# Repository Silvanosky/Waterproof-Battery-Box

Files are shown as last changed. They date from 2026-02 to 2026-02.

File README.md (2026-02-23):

# **🔋 Universal Waterproof Battery Box (100% TPU)**

This project provides a fully parametric OpenSCAD model to generate and 3D print waterproof protection boxes for your batteries (18650, 21700, AA, AAA, etc.).  
**The unique feature of this design is that it is specifically designed to be printed in TPU (flexible filament).** Because the material itself acts as a seal, the box integrates a "double radial seal" system (ridges and grooves) directly into its geometry, eliminating the need to buy and add external O-rings.

## **🌟 Features**

* 💧 **100% TPU Printable**: No external O-ring required. Waterproofing is achieved by the compression of the TPU itself.  
* 🛡️ **Integrated Double Radial Seal**: Two compression rings on the flange guarantee an impenetrable barrier to water.  
* 📏 **Universal and Parametric**: Easily select your battery size in OpenSCAD (18650, 20700, 21700, 26650, AA, AAA) or enter your own custom dimensions.  
* 🪶 **Optimized Weight and Time**: The walls are exactly 1.6mm thick. With a standard 0.4mm nozzle, this perfectly matches 4 perimeters, the ideal ratio to ensure waterproofing without wasting material.  
* 🤲 **Textured Grip**: The body and cap feature a "diamond" (knurled) texture for easy opening/closing, even with wet hands or gloves.

## **🛠️ Prerequisites**

To open, modify, and compile this model, you need:

1. **OpenSCAD** (version 2021.01 or newer recommended).  
2. **The BOSL2 library** installed in your OpenSCAD environment.  
   * *BOSL2 Installation*: Download the library from the official [BOSL2 GitHub](https://github.com/BelfrySCAD/BOSL2) and place the BOSL2 folder in your OpenSCAD libraries folder (Documents/OpenSCAD/libraries/ on Windows/Mac, or \~/.local/share/OpenSCAD/libraries/ on Linux).

## **🚀 Usage (OpenSCAD Customizer)**

1. Open the Waterproof\_Battery\_Box.scad file in OpenSCAD.  
2. Show the **Customizer** window (Menu Window \> Uncheck Hide Customizer).  
3. **Select your battery**: Use the dropdown menu to choose a standard format.  
4. **Display Mode (part)**:  
   * cut: Shows a simulated cross-section view to check the seal fit. *(Recommended for visualizing the design).*  
   * both: Shows both the box and the cap oriented correctly for 3D printing.  
   * box: Shows only the box body to generate the STL.  
   * cap: Shows only the cap to generate the STL.  
5. Press **F6** to render, then click on **"Export as STL"**.

## **🖨️ Printing Recommendations (CRITICAL)**

The design isn't everything. If the print layers aren't perfectly fused, water will leak in. Follow these settings in your Slicer (Cura, PrusaSlicer, OrcaSlicer, etc.):

| Parameter | Recommended Value | Explanation |
| :---- | :---- | :---- |
| **Material** | TPU (95A hardness or softer) | Essential for seal flexibility. |
| **Perimeters (Walls)** | 4 minimum | Waterproofing is achieved by wall thickness (1.6mm). |
| **Seam (Z-Seam)** | Aligned | *Never use "Random"*, as this creates micro-holes. |
| **Temperature** | High range (e.g., 230-235°C) | Guarantees absolute inter-layer fusion. |
| **Flow Rate** | 102% to 105% | Plugs micro-holes and forces layer adhesion. |
| **Supports** | None | The model is designed to print without supports (45° angles). |

## **💡 Usage Tips**

* **First Screwing**: The first assembly might be a bit stiff. Screw and unscrew the cap 3 or 4 times quickly. The friction will heat and soften the TPU, allowing it to "find its place" in the grooves.  
* **Lubrication**: If screwing remains too difficult (TPU on TPU has high friction), apply a micro-drop of **silicone grease** to the threads. This will ease movement without damaging the plastic.

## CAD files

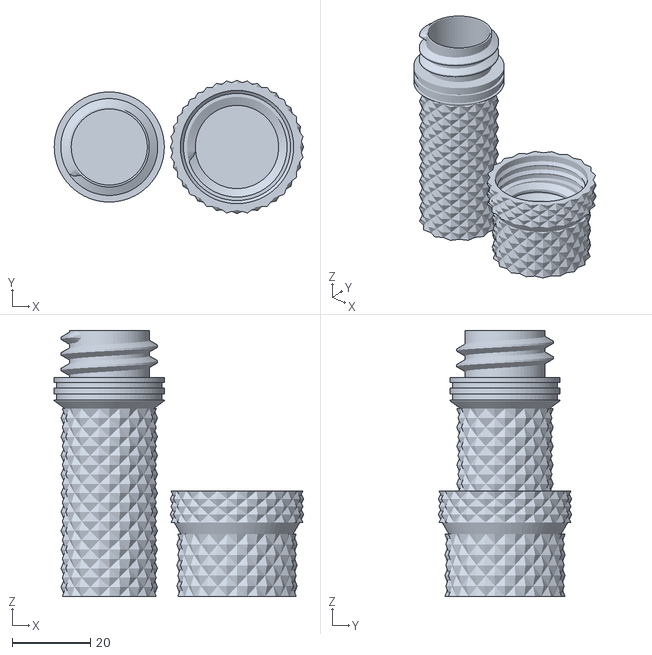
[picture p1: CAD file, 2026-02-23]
Waterproof_Battery_18650.stl
63.9 x 34.2 x 68.1

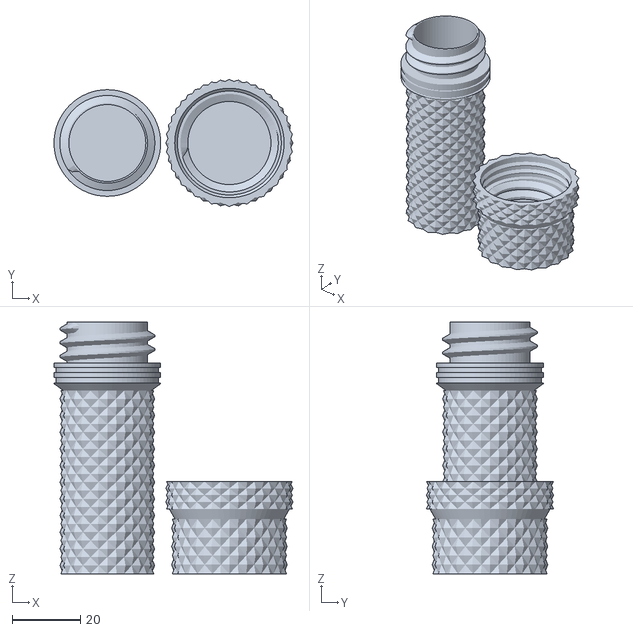
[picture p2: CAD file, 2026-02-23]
Waterproof_Battery_21700.stl
69.9 x 37.2 x 73.6

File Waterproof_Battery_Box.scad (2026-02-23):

include <BOSL2/std.scad>
include <BOSL2/threading.scad>

/* [Sélection de la Batterie] */
// Type de batterie
battery_type = "AA"; // ["18650", "20700", "21700", "26650", "AA", "AAA", "Custom"]

// Diamètre personnalisé (utilisé si "Custom" est sélectionné)
custom_dia = 21.5; 
// Longueur personnalisée (utilisée si "Custom" est sélectionné)
custom_len = 71.0;

/* [Paramètres d'Étanchéité TPU] */
wall_thick = 1.6;  // OPTIMISÉ: 1.6mm = 4 murs parfaits pour étanchéité (plus léger)
base_thick = 1.6;  // OPTIMISÉ: Épaisseur des fonds (gain de poids)
thread_len = 12;   
thread_pitch = 4;  
manual_clearance = 0.8; 

/* [Paramètres d'Affichage] */
part = "cut"; // [box, cap, both, cut]

// --- CALCULS ---
// Détermination des dimensions selon le profil choisi
batt_dia = 
    (battery_type == "18650") ? 18.5 :
    (battery_type == "20700") ? 20.5 :
    (battery_type == "21700") ? 21.5 :
    (battery_type == "26650") ? 26.5 :
    (battery_type == "AA")    ? 14.5 :
    (battery_type == "AAA")   ? 10.5 :
    custom_dia;

batt_len = 
    (battery_type == "18650") ? 65.5 :
    (battery_type == "20700") ? 70.5 :
    (battery_type == "21700") ? 71.0 :
    (battery_type == "26650") ? 65.5 :
    (battery_type == "AA")    ? 50.5 :
    (battery_type == "AAA")   ? 44.5 :
    custom_len;

inner_dia = batt_dia + 1.0;
outer_dia = inner_dia + (2 * wall_thick); 
total_height = batt_len + base_thick + 1; // Ajusté pour le nouveau fond

// Hauteur du bouchon (Calculée ici pour gérer l'inversion d'impression)
cap_h = thread_len + 15; 

// Le filetage est plus large que le tube
base_thread_dia = outer_dia + 2.5; 

// --- PARAMÈTRES DU JOINT RADIAL (SUR LE COTÉ) ---
// La collerette doit être plus large que le filetage pour que le joint passe autour
flange_dia = base_thread_dia + 3.0; // Diamètre de la surface d'étanchéité
flange_height = 8.0; // Hauteur de la zone d'étanchéité verticale

// Positions exactes des joints (depuis le bas de la collerette)
seal_h1 = 3.0; 
seal_h2 = 6.0;

// Diamètre du fond des rainures
seal_groove_depth = 0.6; 

$fn = 64; 

module body() {
    male_thread_d = base_thread_dia - (manual_clearance / 2);
    thread_z_start = total_height - thread_len;
    flange_z_start = thread_z_start - flange_height;

    difference() {
        union() {
            // 1. Tube principal (sous la collerette)
            cyl(d=outer_dia, h=flange_z_start, anchor=BOTTOM, texture="diamonds");
            
            // 2. La Collerette VERTICALE (Flange)
            translate([0, 0, flange_z_start]) 
            cyl(d1=outer_dia, d2=flange_dia, h=2, anchor=BOTTOM); // Transition douce
            
            translate([0, 0, flange_z_start + 2]) 
            cyl(d=flange_dia, h=flange_height-2, anchor=BOTTOM); // Surface verticale pour le joint

            // 3. Le filetage MÂLE (au dessus)
            translate([0, 0, thread_z_start]) 
            threaded_rod(
                d=male_thread_d, 
                l=thread_len, 
                pitch=thread_pitch, 
                orient=TOP, 
                anchor=BOTTOM
            );
        }
        
        // Vide intérieur (décalé de base_thick pour créer le fond)
        up(base_thick) cyl(d=inner_dia, h=total_height+10, anchor=BOTTOM);
        
        // --- RAINURES RADIALES (Sur le coté) ---
        translate([0, 0, flange_z_start + seal_h1]) 
            torus_groove(d=flange_dia, depth=seal_groove_depth);
            
        translate([0, 0, flange_z_start + seal_h2]) 
            torus_groove(d=flange_dia, depth=seal_groove_depth);
    }
}

module cap() {
    female_thread_d = base_thread_dia + (manual_clearance / 2);
    skirt_id = flange_dia + manual_clearance; // Jeu pour glisser sur la collerette
    
    // OPTIMISATION POIDS: On sépare le diamètre de la jupe et le diamètre du haut
    cap_skirt_d = skirt_id + (2 * wall_thick); // Plus large en bas
    cap_upper_d = female_thread_d + (2 * wall_thick); // Affiné en haut
    
    skirt_height = flange_height; 

    difference() {
        // Corps du bouchon (Profile externe allégé)
        union() {
            // Jupe (Bas)
            cyl(d=cap_skirt_d, h=skirt_height, anchor=BOTTOM, texture="diamonds");
            // Transition conique pour l'impression sans support
            translate([0,0, skirt_height])
            cyl(d1=cap_skirt_d, d2=cap_upper_d, h=3, anchor=BOTTOM);
            // Poignée (Haut affiné)
            translate([0,0, skirt_height + 3])
            cyl(d=cap_upper_d, h=cap_h - skirt_height - 3, anchor=BOTTOM, texture="diamonds");
        }
        
        // Intérieur fileté (Haut)
        translate([0,0, skirt_height]) 
        threaded_rod(
            d=female_thread_d, 
            l=cap_h - skirt_height - base_thick, // Arrête le trou à base_thick du sommet
            pitch=thread_pitch, 
            internal=true, 
            orient=TOP, 
            anchor=BOTTOM
        );

        // Intérieur Jupe Lisse (Bas)
        cyl(d=skirt_id, h=skirt_height + 0.1, anchor=BOTTOM);
    }
    
    // --- DENTS RADIALES (À l'intérieur de la jupe) ---
    union() {
        translate([0, 0, seal_h1]) 
            torus_ridge(d=skirt_id, depth=seal_groove_depth + 0.2); 
            
        translate([0, 0, seal_h2]) 
            torus_ridge(d=skirt_id, depth=seal_groove_depth + 0.2);
    }
}

// --- MODULES UTILITAIRES POUR JOINTS RADIAUX ---

module torus_groove(d, depth) {
    difference() {
        cyl(d=d + 1, h=1.5, anchor=CENTER); 
        cyl(d=d - (depth*2), h=3, anchor=CENTER, chamfer=0.8); 
    }
}

module torus_ridge(d, depth) {
    rotate_extrude($fn=64)
    translate([d/2, 0, 0]) 
    polygon([
        [0.1, 1],       
        [-depth, 0],    
        [0.1, -1]       
    ]);
}

// Logique d'affichage
if (part == "box") {
    body();
} else if (part == "cap") {
    // Inversé pour impression (Ouverture vers le HAUT)
    translate([0,0,cap_h]) rotate([180,0,0]) cap();
} else if (part == "both") {
    left(outer_dia/2 + 5) body();
    // Inversé pour impression (Ouverture vers le HAUT)
    right(outer_dia/2 + 5) translate([0,0,cap_h]) rotate([180,0,0]) cap();
} else if (part == "cut") {
    difference() {
        union() {
            body();
            color("red")
            // Simulation position fermée : Le bouchon reste orienté vers le BAS ici
            translate([0,0, total_height - thread_len - flange_height]) 
            zrot(180) 
            cap();
        }
        #cuboid([30, 50, 100], anchor=LEFT+BOTTOM);
    }
}

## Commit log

2026-02-23 Initialize README with project details and usage
    Add detailed project description and usage instructions for the Universal Waterproof Battery Box.
2026-02-23 Add openscad file
    [Waterproof_Battery_Box.scad]
2026-02-23 Add 21700 and 18650 stl
    [Waterproof_Battery_18650.stl, Waterproof_Battery_21700.stl]
